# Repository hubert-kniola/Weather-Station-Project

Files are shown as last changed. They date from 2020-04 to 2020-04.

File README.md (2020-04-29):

# Weather Station

## Instrukcja użytkowania
#### Instrukcja obsługi urządzenia
1. Interfejs graficzny stacji pogodowej obsługuje się czterema przyciskami, które odpowiadają strzałkom (__góra__, __dół__, __lewo__, __prawo__).
1. W celu zrestartowania urządzenia można użyć znajdującego się z tyłu przycisku __reset__ lub odłączyć i podłączyć ponownie zasilanie.
1. Po uruchomieniu stacji znajdujemy się na ekranie głównym, z którego możemy przejść do ekranu opcji za pomocą przycisku __góra__, lub odświeżyć status połączenia z siecią za pomocą dowolnego innego.
1. Na ekranie opcji można się poruszać między wyborami używając __góra__ lub __dół__, wrócić do ekranu głównego za pomocą __lewo__, lub wybrać opcję używając __prawo__.
1. Po zatwierdzeniu każdej z opcji urządzenie wróci do ekranu głównego lub przeniesie nas na ekran dodatkowy w celu wprowadzenia wymaganych danych. Dzieje się tak w przypadku __Connect to WiFi__ oraz __Set time and date__. Opis obsługi tych ustawień widnieje w podpunkcie danego ustawienia poniżej.
1. Opcje dostępne dla użytkownika to:    
   
   1. __Force update__ 		- wymuś aktualizację pogody.
   1. __Connect to WiFi__ 	- wyszukaj dostępne sieci bezprzewodowe.
   
      * Za pomocą __góra__ oraz __dół__ można wybrać sieć do której chcemy się połączyć, jeśli jakakolwiek znajduje się w zasięgu urządzenia.
	  * Za pomocą __lewo__ wracamy do ekranu opcji, a __prawo__ przenosi nas do ekranu wprowadzania hasła, jeśli takowe jest wymagane.
	  
	     Na ekranie wprowadzania hasła wybieramy kolejny znak za pomocą __góra__, przesuwamy się po wprowadzonych znakach za pomocą __lewo__ oraz __prawo__, a wprowadzone dane akceptujemy za pomocą __dół__.
		 
   1. __WiFi Disconnect__ 	- odłącz się od aktualnej sieci bezprzewodowej.
   1. __Set time and date__ - ręcznie ustaw datę i czas urządzenia.
   
      Za pomocą __góra__ zmieniamy wartość pola, które wskazuje kursor, przesuwamy się po polach za pomocą __lewo__ oraz __prawo__, a dane akceptujemy z użyciem __dół__.
	  
	  Aby wyjść bez dokonywania zmian wprowadzamy błędne dane, lub zostawiamy pola w domyślnym ustawieniu.
	   
   1. __Clear SD data__ 	- wyczyść wszystkie logi pogody dostępne na urządzeniu.
   1. __Toggle RGB usage__ 	- przełącz używanie przez urządzenie diody led.

#### Instrukcja obsługi strony internetowej
1. Aby poprawnie uzyskać dostęp do danych udostępnianych przez stację pogodową niezbędne jest posiadanie sprawnego połączenia internetowego. Bez niego strona internetowa będzie wyświetlana jako czysty html, bez dodatkowej szaty wizualnej.
1. Użytkownik po podłączeniu do sieci bezprzewodowej wchodząc pod adres IP nadany stacji w podsieci routera znajdzie się na stronie głównej.
1. Główna strona zawiera umieszone pod napisem `Weather Station` odnośniki do następujących podstron: `data`, `about`. Obecne poniżej pole `Current Weather` po pobraniu danych z urządzenia wyświetli aktualną pogodę oraz zsynchronizuje czas urządzenia z czasem systemu stacji.
1. Wciśnięcie przez użytkownika odnośnika `data` skutkować będzie przeniesieniem na podstronę, gdzie została udostępniona możliwość podglądu starszych odczytów pogody znajdujących się w pamięci urządzenia. Po pobraniu ilości dostępnych danych użytkownik zostanie poproszony o wpisanie zakresu danych do pobrania.
1. Wciśnięcie przez  użytkownika odnośnika `about` powoduję przejście na podstronę poświęconą autorom projektu oraz informacjom ogólnym na temat stacji pogodowej.
## O projekcie
### Celem projektu było własnoręczne utworzenie stacji pogodowej przy zastosowaniu następujących elementów:
* Moduł WiFi (mikrokontroler ESP8266)
* Moduł karty SD
* Czujnik temperatury i wilgotności powietrza DHT11
* Dioda RGB
* Wyświetlacz LCD 4x20 ze sterownikiem HD44780
* Przyciski Tact-Switch
* Powerbank
* Mikrokontroler STM32F407VG Discovery

### Technologia zastosowana w projekcie:
* Język C - oprogramowanie płytki STM
* Język JavaScript - skryptowa obsługa strony internetowej
* HTML 5 - struktura strony internetowej
* CSS 3 - wygląd strony internetowej
* RESTlike API - struktura działania serwera HTTP
* Fetch API - pobieranie informacji z serwera HTTP
* Bootstrap 4 - responsywność strony internetowej

### Biblioteki języka C użyte w projekcie:
* FatFs by elm-chan

### Prezentacja [elementów](https://github.com/PUT-PTM-2020/P14/tree/master/stm/stmphotos) hardware projektu:

<p align="center">
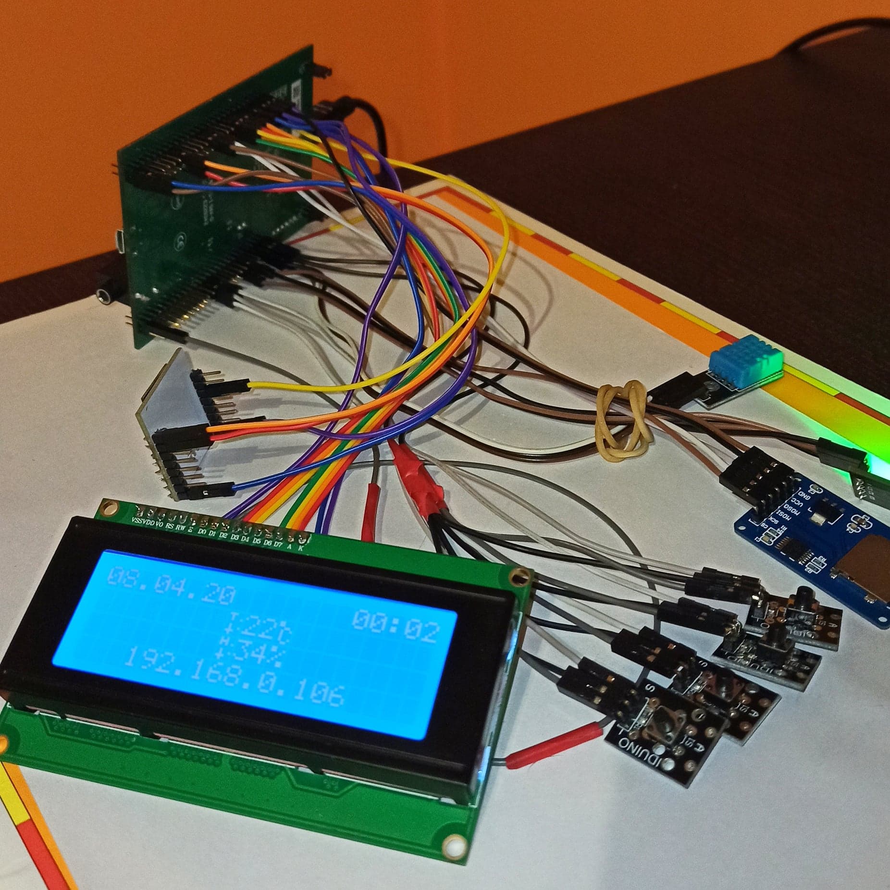
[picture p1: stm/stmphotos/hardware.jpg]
  
</p>

### [Strona](https://github.com/PUT-PTM-2020/P14/tree/master/website/wwwphotos) internetowa została stworzona w celu odczytywania danych na temat pogody z serwera HTTP mikrokontrolera:

<p align="center">
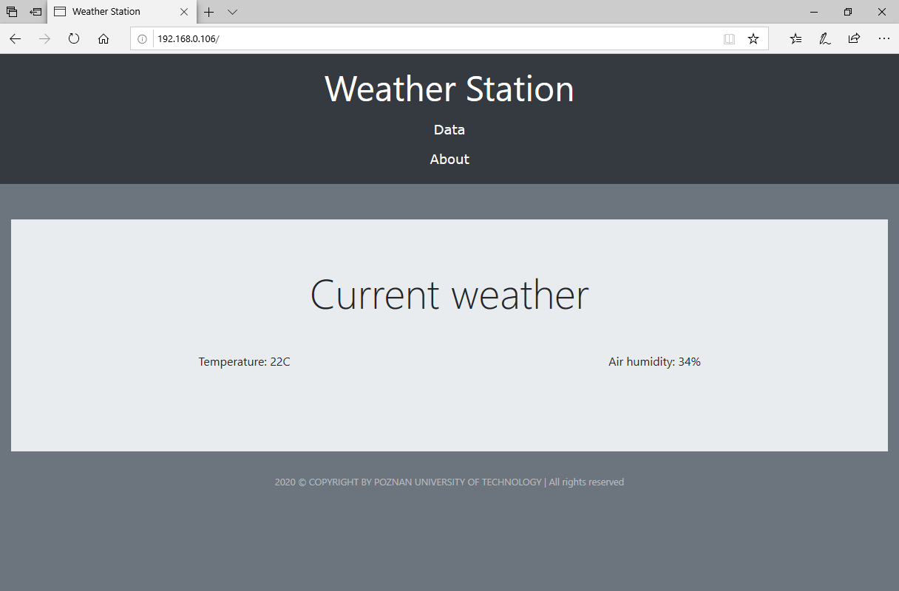
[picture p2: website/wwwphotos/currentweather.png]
  
</p>
<p align="center">
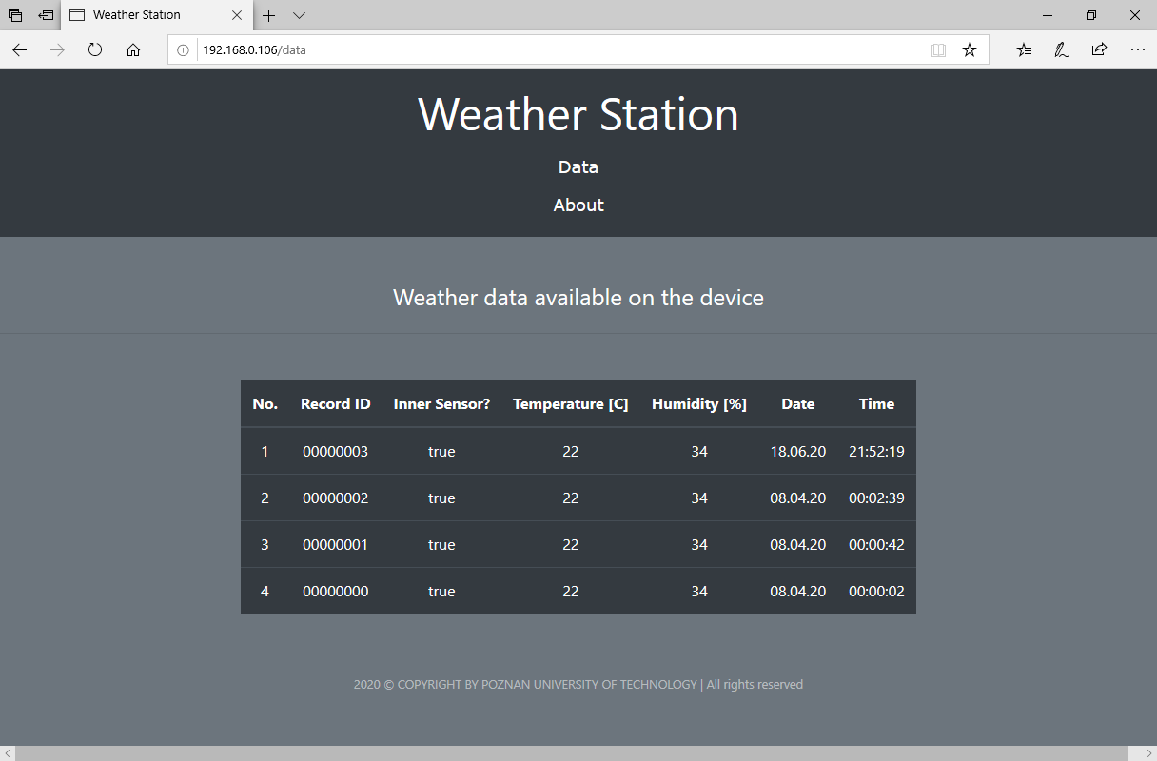
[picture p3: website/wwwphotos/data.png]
Dane
  
</p>
<p align="center">
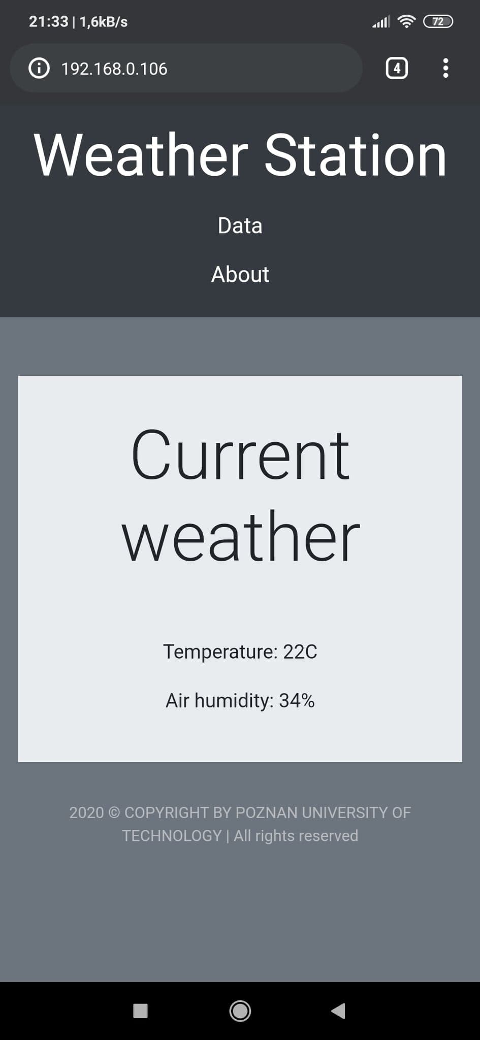
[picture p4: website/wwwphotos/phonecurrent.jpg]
Wersja mobilna1
  
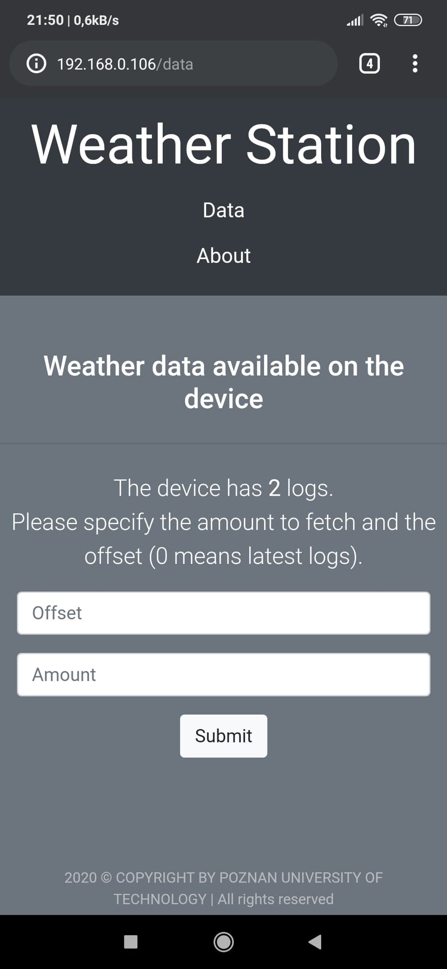
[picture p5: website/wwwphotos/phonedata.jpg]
Wersja mobilna2
  
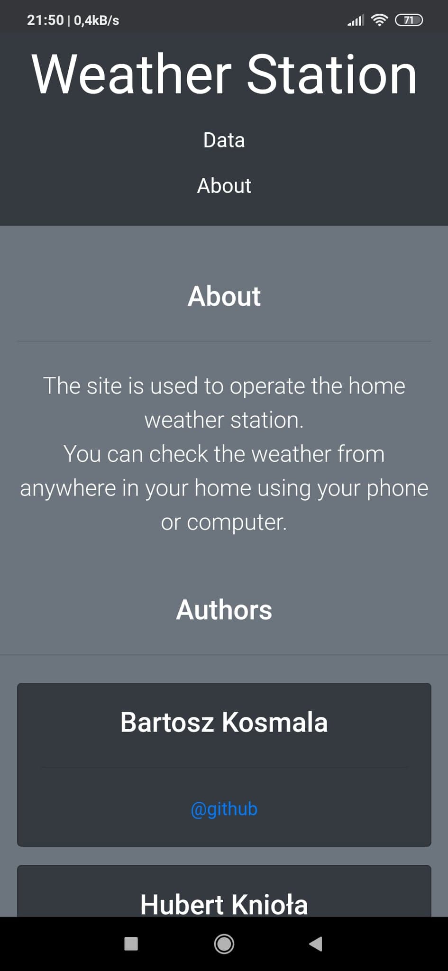
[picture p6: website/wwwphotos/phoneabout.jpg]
Wersja mobilna3
  
</p>

### Obudowa stacji pogodowej została wykonana przy użyciu programu Autodesk Fusion 360.  Fragmenty [obudowy](https://github.com/PUT-PTM-2020/P14/tree/master/model3d/Photo3D): 

<p align="center">
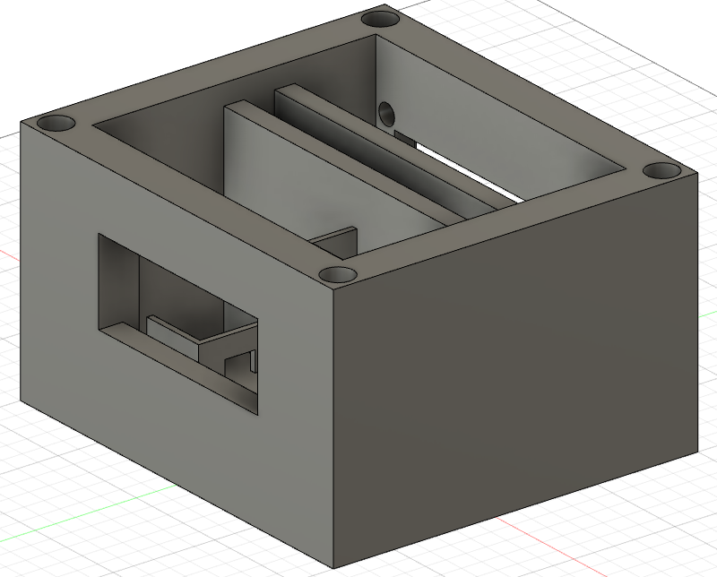
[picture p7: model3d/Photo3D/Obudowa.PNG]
Obudowa
  
</p>
<p align="center">
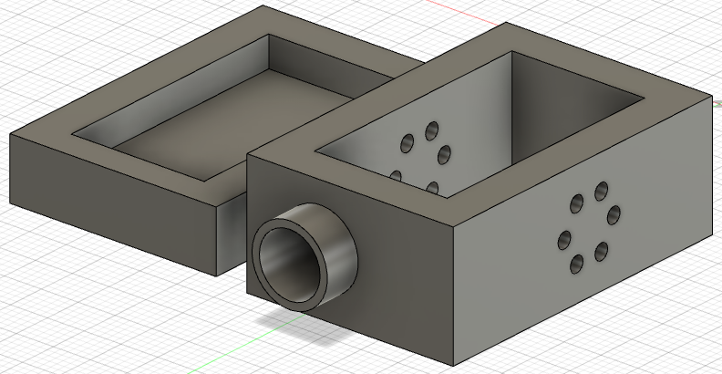
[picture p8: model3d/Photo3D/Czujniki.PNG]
Czujniki
  
</p>

## Autorzy
* Hubert Knioła
* Bartosz Kosmala
> 2020 PUT

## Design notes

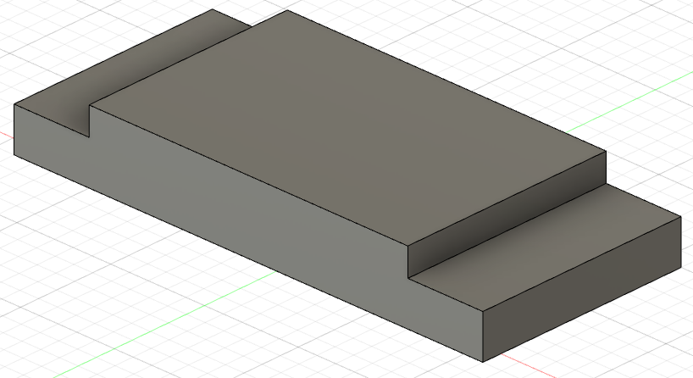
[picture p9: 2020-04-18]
model3d/Photo3D/ObudowaWkładka.PNG

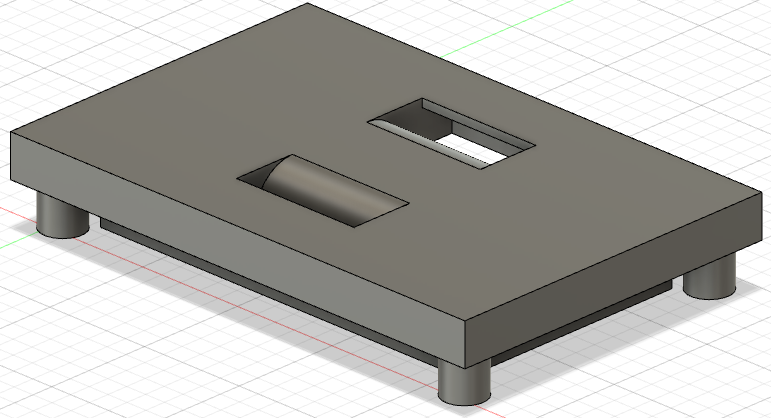
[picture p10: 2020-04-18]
model3d/Photo3D/ObudowaOkienko.PNG

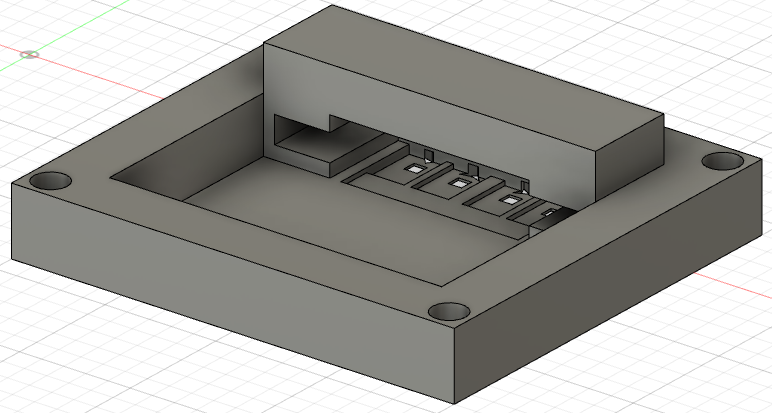
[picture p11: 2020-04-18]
model3d/Photo3D/ObudowaPokrywka.PNG

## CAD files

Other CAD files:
model3d/Czujniki v1.f3d
model3d/Obudowa v7.f3d
model3d/ObudowaOkienko v1.f3d
model3d/ObudowaPokrywka v4.f3d
model3d/ObudowaWkładka v1.f3d

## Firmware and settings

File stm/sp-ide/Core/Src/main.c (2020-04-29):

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

/* Includes ------------------------------------------------------------------*/
#include "main.h"

/* USER CODE BEGIN Includes */

#include "SP_RGB.h"
#include "SP_LCD.h"
#include "SP_THS.h"
#include "SP_SD.h"
#include "SP_NET.h"
#include "SP_MENU.h"
#include "SP_HTTP.h"

#include <stdbool.h>

/* USER CODE END Includes */

RTC_HandleTypeDef hrtc;

SPI_HandleTypeDef hspi1;

TIM_HandleTypeDef htim2;
TIM_HandleTypeDef htim3;
TIM_HandleTypeDef htim4;

UART_HandleTypeDef huart3;

/* USER CODE BEGIN PV */

StateEnum M_State;
ModeEnum M_Mode;

/* USER CODE END PV */

void SystemClock_Config(void);
static void MX_GPIO_Init(void);
static void MX_RTC_Init(void);
static void MX_SPI1_Init(void);
static void MX_TIM2_Init(void);
static void MX_TIM3_Init(void);
static void MX_TIM4_Init(void);
static void MX_USART3_UART_Init(void);
/**
  * @brief  The application entry point.
  * @retval int
  */
int main(void)
{
  /* MCU Configuration--------------------------------------------------------*/

  /* Reset of all peripherals, Initializes the Flash interface and the Systick. */
  HAL_Init();

  /* Configure the system clock */
  SystemClock_Config();

  /* Initialize all configured peripherals */
  MX_GPIO_Init();
  MX_RTC_Init();
  MX_SPI1_Init();
  MX_TIM2_Init();
  MX_TIM3_Init();
  MX_TIM4_Init();
  MX_USART3_UART_Init();
  /* USER CODE BEGIN 2 */

	/* Module Init */
	HAL_TIM_Base_Start_IT(&htim2); /* RGB Tim Init */
	HAL_TIM_PWM_Start(&htim2, TIM_CHANNEL_1);
	HAL_TIM_PWM_Start(&htim2, TIM_CHANNEL_2);
	HAL_TIM_PWM_Start(&htim2, TIM_CHANNEL_3);

	HAL_TIM_Base_Start_IT(&htim3); /* System Update Tim Init */
	HAL_TIM_Base_Start(&htim4); /* THS syncro clock */

	RGB_Init();
	LCD_Init();
	THS_Init();
	SD_Init();
	NET_Init();
	MENU_Init();
  /* USER CODE END 2 */

  /* Infinite loop */
  /* USER CODE BEGIN WHILE */

	LCD_ClearScreen();

	while (1) {
		if (M_State == ST_Clock) {
			MENU_Clock();
		}

		MENU_HandleInput();

    /* USER CODE END WHILE */

    /* USER CODE BEGIN 3 */
	}
  /* USER CODE END 3 */
}

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
/* USER CODE BEGIN 4 */
/* SP Callback Definitions */
void HAL_TIM_PeriodElapsedCallback(TIM_HandleTypeDef *htim) {
	if (htim->Instance == TIM2) {
		RGB_Update();
		THS_ErrorClock();
	} else if (htim->Instance == TIM3 && M_State == ST_Clock) {
		MENU_IncTick();
	}
}

void HAL_UART_RxCpltCallback(UART_HandleTypeDef *uart) {
	NET_HandleUART_IT();
}
/* USER CODE END 4 */
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


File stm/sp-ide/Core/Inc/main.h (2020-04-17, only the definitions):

#define LCD_D6_Pin GPIO_PIN_2
#define LCD_D6_GPIO_Port GPIOE
#define LCD_D7_Pin GPIO_PIN_3
#define LCD_D7_GPIO_Port GPIOE
#define LCD_RS_Pin GPIO_PIN_4
#define LCD_RS_GPIO_Port GPIOE
#define LCD_RW_Pin GPIO_PIN_5
#define LCD_RW_GPIO_Port GPIOE
#define LCD_E_Pin GPIO_PIN_6
#define LCD_E_GPIO_Port GPIOE
#define LCD_Screen_Pin GPIO_PIN_15
#define LCD_Screen_GPIO_Port GPIOC
#define THS_Sensor1_Pin GPIO_PIN_0
#define THS_Sensor1_GPIO_Port GPIOC
#define THS_Sensor2_Pin GPIO_PIN_1
#define THS_Sensor2_GPIO_Port GPIOC
#define RGB_Green_Pin GPIO_PIN_1
#define RGB_Green_GPIO_Port GPIOA
#define RGB_Blue_Pin GPIO_PIN_2
#define RGB_Blue_GPIO_Port GPIOA
#define RGB_Red_Pin GPIO_PIN_5
#define RGB_Red_GPIO_Port GPIOA
#define MENU_Btn1_Pin GPIO_PIN_7
#define MENU_Btn1_GPIO_Port GPIOE
#define MENU_Btn2_Pin GPIO_PIN_8
#define MENU_Btn2_GPIO_Port GPIOE
#define MENU_Btn3_Pin GPIO_PIN_9
#define MENU_Btn3_GPIO_Port GPIOE
#define MENU_Btn4_Pin GPIO_PIN_10
#define MENU_Btn4_GPIO_Port GPIOE
#define STM_Green_Pin GPIO_PIN_12
#define STM_Green_GPIO_Port GPIOD
#define STM_Orange_Pin GPIO_PIN_13
#define STM_Orange_GPIO_Port GPIOD
#define STM_Red_Pin GPIO_PIN_14
#define STM_Red_GPIO_Port GPIOD
#define STM_Blue_Pin GPIO_PIN_15
#define STM_Blue_GPIO_Port GPIOD
#define HTTP_TX_Pin GPIO_PIN_10
#define HTTP_TX_GPIO_Port GPIOC
#define HTTP_RX_Pin GPIO_PIN_11
#define HTTP_RX_GPIO_Port GPIOC
#define SD_SCK_Pin GPIO_PIN_3
#define SD_SCK_GPIO_Port GPIOB
#define SD_MISO_Pin GPIO_PIN_4
#define SD_MISO_GPIO_Port GPIOB
#define SD_MOSI_Pin GPIO_PIN_5
#define SD_MOSI_GPIO_Port GPIOB
#define LCD_D4_Pin GPIO_PIN_0
#define LCD_D4_GPIO_Port GPIOE
#define LCD_D5_Pin GPIO_PIN_1
#define LCD_D5_GPIO_Port GPIOE
#define UART_PRI 1

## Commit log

2020-03-22 led module done
2020-04-18 bug fix after usage tests
    [SP_LCD.c, SP_MENU.c, SP_NET.c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]
2020-04-26 v1.1
    * fixed wrong month on time sync
    * fixed esp wifi broadcast
    * fixed wifi list bug
    * added open network auto-connect
    * added async json fetching
    * minor visual improvements
    * website now syncs time before forcing weather update
    * disabled rtc auto-calibration (need to test)
    [SP_LCD.c, SP_MENU.c, SP_NET.c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]

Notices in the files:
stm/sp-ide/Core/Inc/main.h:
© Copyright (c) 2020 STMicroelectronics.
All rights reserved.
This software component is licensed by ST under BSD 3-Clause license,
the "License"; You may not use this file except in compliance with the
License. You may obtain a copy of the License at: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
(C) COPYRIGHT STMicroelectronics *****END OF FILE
